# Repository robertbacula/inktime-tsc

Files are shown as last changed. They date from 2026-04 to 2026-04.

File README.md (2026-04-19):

# InkTime v6 - Smartwatch Open Hardware cu E-Paper

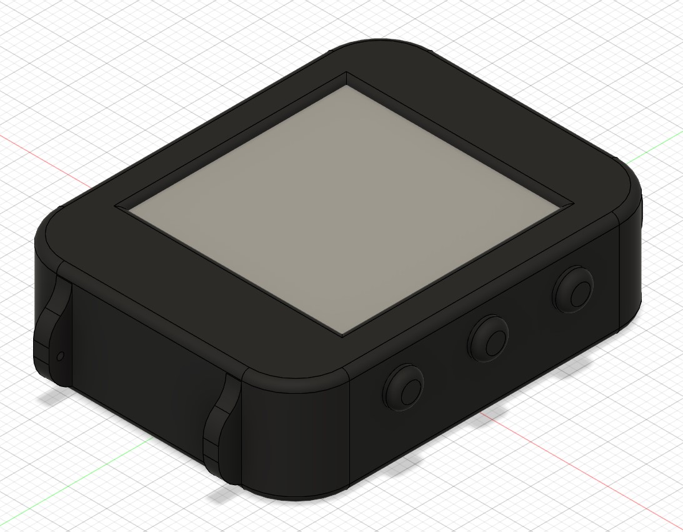
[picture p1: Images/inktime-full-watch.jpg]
InkTime - vedere generala


InkTime v6 este un proiect hardware open-source de smartwatch bazat pe nRF52840, optimizat pentru consum redus, autonomie mare si integrare mecanica compacta. Documentatia de mai jos este structurata pentru review tehnic si include arhitectura sistemului, BOM, maparea pinilor, analiza de consum si observatii de design.

## Cuprins

- [Diagrama bloc](#diagrama-bloc)
- [Bill of Materials (BOM)](#bill-of-materials-bom)
- [Functionalitate hardware detaliata](#functionalitate-hardware-detaliata)
- [Maparea pinilor nRF52840](#maparea-pinilor-nrf52840)
- [Analiza consumului de energie](#analiza-consumului-de-energie)
- [Design PCB si integrare mecanica](#design-pcb-si-integrare-mecanica)
- [Design log si observatii pentru review](#design-log-si-observatii-pentru-review)
- [Structura repository-ului](#structura-repository-ului)
- [Licenta](#licenta)

## Diagrama bloc

Diagrama bloc este prezentata ca imagine:

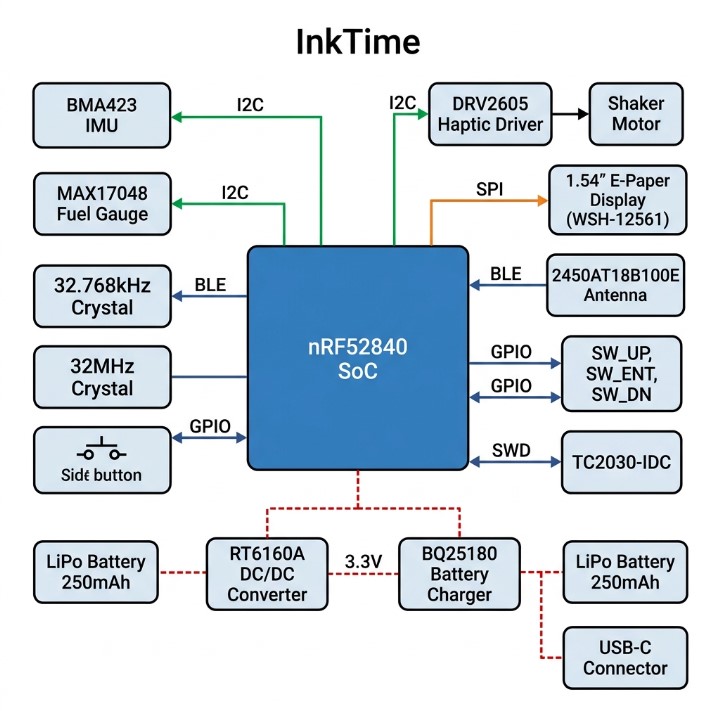
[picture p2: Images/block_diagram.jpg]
Diagrama bloc InkTime


Flux de functionare:

1. USB-C alimenteaza incarcatorul BQ25180 si bateria LiPo.
2. Din baterie se genereaza rail-ul de 3.3V (RT6160A), comutat catre sarcina prin PMOS.
3. nRF52840 colecteaza date de la IMU/fuel gauge si controleaza display-ul prin SPI.
4. Pentru notificari locale, nRF52840 activeaza DRV2605 care comanda motorul haptic.
5. BLE asigura schimb de date si configurare cu telefonul.

## Bill of Materials (BOM)

Tabelul de mai jos acopera componentele principale. Pentru pasivele individuale, consultati schema si listele de asamblare exportate din CAD.

| # | Ref  | Componenta | Cod / Valoare | JLC Parts | Datasheet |
| --- | ---- | --- | --- | --- | --- |
| 1 | U1 | MCU BLE | nRF52840-QIAA | [C190794](https://jlcpcb.com/parts/componentSearch?isSearch=true&searchTxt=nRF52840) | [nRF52840 PS](https://infocenter.nordicsemi.com/pdf/nRF52840_PS_v1.8.pdf) |
| 2 | IC2  | Li-Ion Charger | BQ25180YBGR | [C2682092](https://jlcpcb.com/parts/componentSearch?isSearch=true&searchTxt=BQ25180) | [TI BQ25180](https://www.ti.com/lit/ds/symlink/bq25180.pdf) |
| 3 | IC9  | Buck DC/DC | RT6160AWSC | [C2828036](https://jlcpcb.com/parts/componentSearch?isSearch=true&searchTxt=RT6160A) | [Richtek RT6160A](https://www.richtek.com/assets/product_file/RT6160A/DS6160A-05.pdf) |
| 4 | U3 | Fuel Gauge | MAX17048G+T10 | [C2682766](https://jlcpcb.com/parts/componentSearch?isSearch=true&searchTxt=MAX17048) | [MAX17048/49](https://datasheets.maximintegrated.com/en/ds/MAX17048-MAX17049.pdf) |
| 5 | IC3  | IMU | BMA423 | [C2831316](https://jlcpcb.com/parts/componentSearch?isSearch=true&searchTxt=BMA423) | [Bosch BMA423](https://www.bosch-sensortec.com/products/motion-sensors/accelerometers/bma423/) |
| 6 | IC1  | Driver haptic | DRV2605YZFR | [C527680](https://jlcpcb.com/parts/componentSearch?isSearch=true&searchTxt=DRV2605) | [TI DRV2605](https://www.ti.com/lit/ds/symlink/drv2605.pdf) |
| 7 | D1 | Protectie ESD USB | USBLC6-2SC6Y | [C7519](https://jlcpcb.com/parts/componentSearch?isSearch=true&searchTxt=USBLC6-2SC6Y) | [ST USBLC6-2](https://www.st.com/resource/en/datasheet/usblc6-2.pdf) |
| 8 | Q1 | PMOS load switch | DMG2305UX-7 | [C150812](https://jlcpcb.com/parts/componentSearch?isSearch=true&searchTxt=DMG2305UX) | [DMG2305UX](https://www.diodes.com/assets/Datasheets/DMG2305UX.pdf) |
| 9 | Q3 | N-MOS (motor/periferic) | SI1308EDL-T1-GE3  | [C515086](https://jlcpcb.com/parts/componentSearch?isSearch=true&searchTxt=SI1308EDL) | [SI1308EDL](https://www.vishay.com/docs/68743/si1308edl.pdf) |
| 10  | J1 | FPC conector EPD | 503480-2400 (24p) | [C585393](https://jlcpcb.com/parts/componentSearch?isSearch=true&searchTxt=503480-2400) | [Molex 503480](https://www.molex.com/pdm_docs/sd/5034802400_sd.pdf) |
| 11  | J4 | USB-C conector | KH-TYPE-C-16P | [C2765186](https://jlcpcb.com/parts/componentSearch?isSearch=true&searchTxt=KH-TYPE-C-16P) | [USB Type-C Spec](https://www.usb.org/document-library/usb-type-cr-cable-and-connector-specification-release-22) |
| 12  | ANT1 | Antena chip 2.4GHz | 2450AT18B100E | [Search JLC](https://jlcpcb.com/parts/componentSearch?isSearch=true&searchTxt=2450AT18B100E) | [Johanson 2450AT18B100E](https://www.johansontechnology.com/datasheets/2450AT18B100E.pdf) |
| 13  | J2 | Header debug | TC2030-IDC | [Search JLC](https://jlcpcb.com/parts/componentSearch?isSearch=true&searchTxt=TC2030) | [Tag-Connect TC2030](https://www.tag-connect.com/wp-content/uploads/bsk-pdf-manager/TC2030-IDC-NL-10_NL_1.pdf) |
| 14  | X1 | Cristal HF | 32MHz | [Search JLC](https://jlcpcb.com/parts/componentSearch?isSearch=true&searchTxt=32MHz%20crystal%202016) | [Exemplu 32MHz](https://www.ecsxtal.com/store/pdf/ECS-160-12-33Q.pdf) |
| 15  | X2 | Cristal LF | 32.768kHz | [Search JLC](https://jlcpcb.com/parts/componentSearch?isSearch=true&searchTxt=32.768kHz%20crystal%203215) | [Exemplu 32.768kHz](https://www.abracon.com/Resonators/ABS07.pdf) |

## Functionalitate hardware detaliata

### 1) Procesare si conectivitate - nRF52840

- CPU: ARM Cortex-M4F @ 64MHz
- Memorie: 1MB Flash, 256KB RAM
- Radio: BLE 5.x la 2.4GHz
- Interfete folosite in proiect: SPI, I2C, GPIO, USB FS, SWD

Rol functional:

- ruleaza logica aplicatiei si machine-state-ul ceasului
- centralizeaza datele de la senzori
- controleaza secventa de refresh pentru e-paper
- gestioneaza notificari BLE si feedback haptic

### 2) Display e-paper (1.54") + etaj driver

Display-ul e-paper este comandat pe SPI, cu semnale separate de control (`DC`, `RST`, `BUSY`, `CS`). Avantajul major este consumul aproape zero in stare statica; energia se consuma aproape exclusiv la refresh.

Interfata:

- SPI pentru payload grafic
- GPIO pentru sincronizare/stare (`BUSY`) si comenzi

### 3) IMU BMA423

IMU-ul este conectat pe I2C si utilizat pentru:

- step counting
- wake-on-motion / wrist raise
- detectie evenimente contextuale

Poate genera intreruperi catre MCU pentru reducerea polling-ului si optimizare de consum.

### 4) Management baterie - BQ25180 + MAX17048 + RT6160A

- BQ25180: incarcare LiPo din VBUS (USB-C)
- MAX17048: monitorizare starea bateriei (SOC, tensiune)
- RT6160A: conversie stabila catre 3.3V pentru sistem

Acest lant permite operare corecta atat pe USB, cat si pe baterie, cu telemetrie energetica pentru estimarea autonomiei.

### 5) Haptic - DRV2605 + motor

DRV2605 genereaza profile haptice controlate de MCU (I2C + trigger), iar etajul de putere comuta motorul pentru feedback la notificari, alarme si interactiuni UI.

### 6) USB-C, protectie ESD si debug

- USB-C ofera VBUS pentru incarcare si (optional) date USB FS.
- USBLC6-2 reduce riscul de defect la descarcari electrostatice pe D+/D-.
- Header-ul TC2030 expune SWD pentru flash/debug si test de productie.

## Maparea pinilor nRF52840

Maparea de mai jos este cea utilizata in schema proiectului pentru functiile principale.

| Pin nRF52840  | Semnal / Componenta | Interfata | Directie | Motiv alegere |
| --- | --- | --- | --- | --- |
| P0.02 | EPD_SCK | SPI | Out | Clock stabil pentru transfer display |
| P0.03 | EPD_MOSI | SPI | Out | Date catre e-paper |
| P0.28 | EPD_MISO | SPI | In | Citire status/date display |
| P0.29 | EPD_CS | GPIO/SPI  | Out | Selectie dispozitiv e-paper |
| P0.04 | EPD_DC | GPIO | Out | Selectie data/comanda |
| P0.05 | EPD_RST | GPIO | Out | Reset hardware display |
| P0.06 | EPD_BUSY | GPIO | In | Sincronizare pe stare busy |
| P0.26 | I2C_SDA | I2C | I/O | Magistrala comuna senzori/power |
| P0.27 | I2C_SCL | I2C | Out | Clock I2C comun |
| P0.13 | SW_UP | GPIO IRQ  | In | Buton up, interrupt la apasare |
| P0.14 | SW_ENT | GPIO IRQ  | In | Buton enter, UI action |
| P0.15 | SW_DN | GPIO IRQ  | In | Buton down, navigare |
| P0.18 | USB_D- | USB FS | I/O | Linie USB dedicata (minus) |
| P0.20 | USB_D+ | USB FS | I/O | Linie USB dedicata (plus) |
| P0.00 / P0.01 | XL1 / XL2 | LFCLK | I/O | Cristal 32.768kHz pentru RTC low-power |
| XC1 / XC2 | X1 32MHz | HFCLK | I/O | Ceas principal CPU/RF |
| SWDIO | SWD_DATA | SWD | I/O | Programare si debugging |
| SWDCLK | SWD_CLK | SWD | In | Ceas SWD |
| SWO | SWO_TRACE | SWD | Out | Trace/telemetrie debug |
| ANT | Antena BLE | RF | Out | Iesire RF catre retea de matching |

Rationale general pentru mapare:

1. SPI-ul display-ului este grupat compact pentru rutare scurta si integritate buna a semnalelor.
2. Toate perifericele lente (IMU, fuel gauge, haptic) sunt pe I2C comun pentru economie de pini.
3. Butoanele sunt pe GPIO-uri configurabile cu intreruperi, pentru wake-up din low power.
4. USB foloseste pinii dedicati ai MCU pentru compatibilitate fizica si software.

## Analiza consumului de energie

Estimare orientativa pe scenariu "smartwatch normal" (ecran actualizat periodic, BLE advertising, wake pe evenimente):

| Bloc | Curent activ | Curent sleep/idle | Duty cycle estimat | Curent mediu |
| --- | ---: | ---: | ---: | ---: |
| nRF52840 (CPU + BLE) |  3.2mA-4.8mA | 1.5uA | 5-6% | ~210uA |
| E-Paper (refresh) | ~15mA | ~0uA static | 0.5% | ~75uA |
| BMA423 | ~150uA | ~14uA | 10% activ | ~28uA |
| MAX17048 | 23uA | 23uA | 100% | 23uA |
| DRV2605 + motor | ~50mA varf | ~0.25uA | 0.1% | ~50uA |
| RT6160A quiescent | - | ~25uA | 100% | 25uA |
| **Total estimat** | - | - | - | **~410uA** |

Pentru baterie de 250mAh:

- autonomie teoretica: `250mAh / 0.41mA = ~609h` (~25 zile)
- cu profil agresiv de sleep si refresh rar: 30-40+ zile (in functie de firmware si trafic BLE)

## Design PCB si integrare mecanica

### PCB

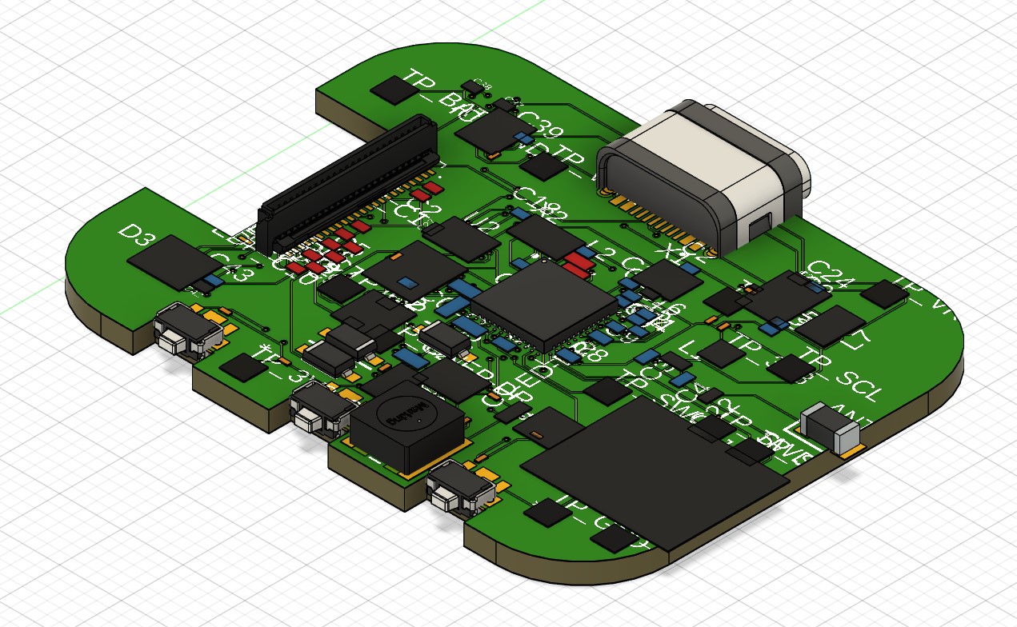
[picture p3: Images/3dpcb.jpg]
PCB 3D


- layout realizat in fisierele `Hardware/project-tsc.sch` si `Hardware/project-tsc-2d-pcb.brd`
- topologia include zona RF dedicata, sectiune alimentare separata si trasee de semnal scurte catre conectorul EPD
- protectie ESD pe USB si puncte de test pentru bring-up

### Integrare mecanica

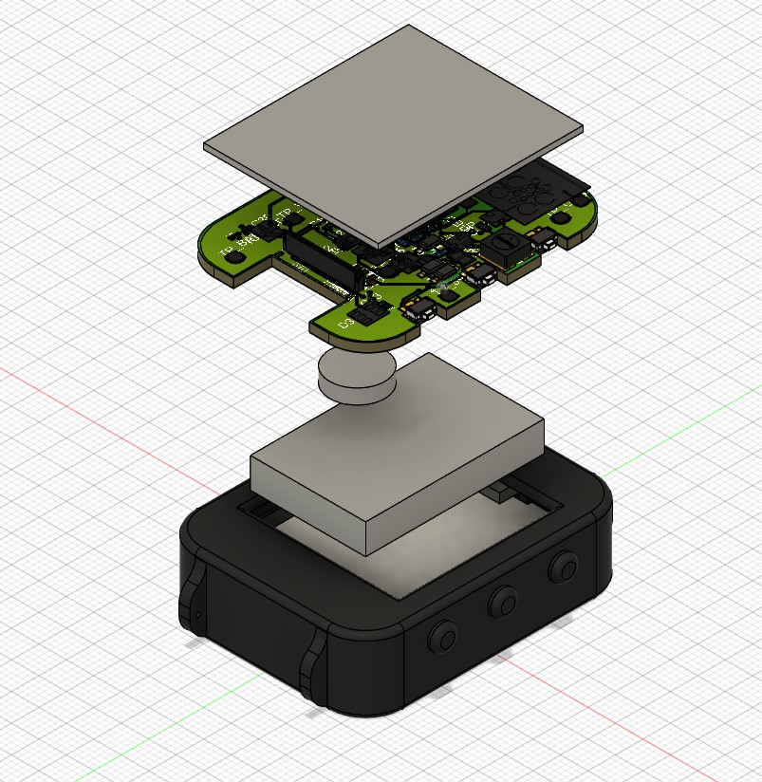
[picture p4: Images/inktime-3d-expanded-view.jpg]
Vedere asamblare extinsa

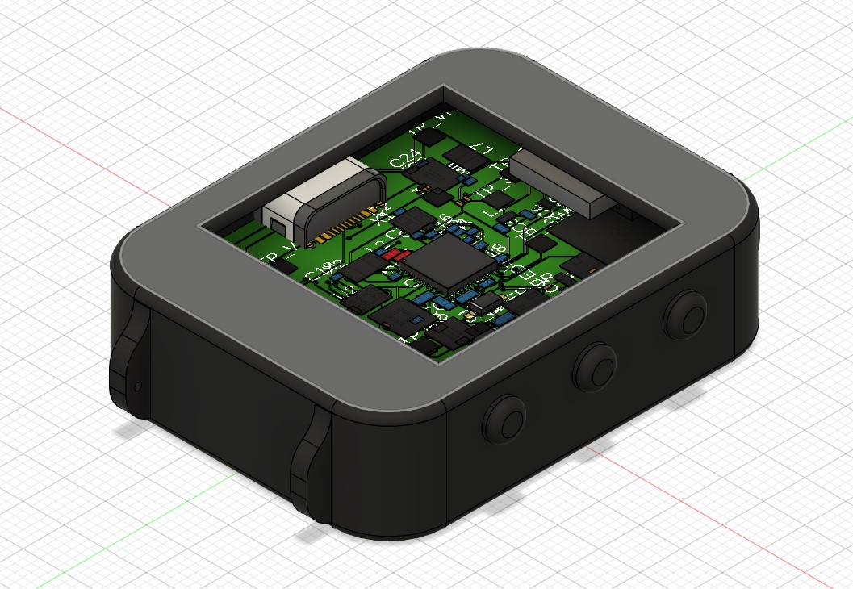
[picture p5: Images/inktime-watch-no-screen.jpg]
Vedere fara ecran


- modele 3D disponibile in `Mechanical/InkTime3D.f3z` si `Mechanical/InkTime3D.step`
- verificari importante: inaltime baterie, spatiu FPC display, pozitie butoane laterale, clearance pentru motorul haptic

## Design log si observatii pentru review

Design log (sintetic):

1. Definire arhitectura (MCU, putere, senzori, afisaj)
2. Captura schema si validare ERC
3. Placement cu prioritizare RF/power/display
4. Routing + optimizari DRC/ground return
5. Export productie si validare mecanica 3D

Observatii utile pentru review:

- verificati zona antenei: keepout de cupru sub antenna + matching network conform recomandari vendor
- confirmati polaritatea pentru bateria LiPo si sensul diodei Schottky
- verificati secventa de power-up EPD in firmware, pentru a evita refresh instabil
- recomandat test incremental: power rail -> SWD -> I2C -> EPD -> BLE

## Structura repository-ului

```text
inktime-tsc/
|- Hardware/
|  |- project-tsc.sch
|  |- project-tsc-2d-pcb.brd
|- Images/
|  |- 3dpcb.jpg
|  |- inktime-full-watch.jpg
|  |- inktime-3d-expanded-view.jpg
|  |- inktime-watch-no-screen.jpg
|- Manufacturing/
|  |- inktime_gerber.zip
|- Mechanical/
|  |- InkTime3D.f3z
|  |- InkTime3D.step
|- LICENSE
|- README.md
```

## Licenta

Proiectul este distribuit conform fisierului `LICENSE` din acest repository.

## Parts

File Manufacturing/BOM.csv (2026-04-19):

Part | Value | Device | Footprint Name | Detailed Description | ARROW_PART_NUMBER | ARROW_PRICE-STOCK | AVAILABILITY | CHECK_PRICES | COPYRIGHT | DESCRIPTION | DIGI-KEY_PART_NUMBER_1 | DIGI-KEY_PART_NUMBER_2 | DIGI-KEY_PART_NUMBER_3 | HEIGHT | JLCPCB | MANUFACTURER_NAME | MANUFACTURER_PART_NUMBER | MF | MFR_NAME | MOUSER_PART_NUMBER | MOUSER_PRICE-STOCK | MP | PACKAGE | POPULARITY | PRICE | PROD_ID | PURCHASE-URL | SNAPEDA_LINK | TP_SIGNAL_NAME | VALUE
ANT1 | 2450AT18B100E | 2450AT18B100E_2450AT18B100E | 2450AT18B100E_ANTC3216X140N | Antennas 2.45GHz ANTENNA | 2450AT18B100E | https://www.arrow.com/en/products/2450at18b100e/johanson-dielectrics?utm_currency=USD&region=nac |  |  |  | Antennas 2.45GHz ANTENNA |  |  |  | 1.4mm |  | JOHANSON TECHNOLOGY | 2450AT18B100E |  |  | 609-2450AT18B100E | https://www.mouser.co.uk/ProductDetail/Johanson-Technology/2450AT18B100E?qs=yCnrNFeXz%252Bh5MFsFIXGZGA%3D%3D
C1 | 12pF | NORDIC_NRF_3_CAPACITOR_0201_L | NORDIC_NRF_3_RESC0201_L | Generic chip capacitor
C1-ED-DR | 10uF | NORDIC_NRF_3_CAPACITOR_0402_N | NORDIC_NRF_3_RESC0402_N | Generic chip capacitor
C2 | 12pF | NORDIC_NRF_3_CAPACITOR_0201_L | NORDIC_NRF_3_RESC0201_L | Generic chip capacitor
C2-EP-DR | 4.7uF | NORDIC_NRF_3_CAPACITOR_0402_N | NORDIC_NRF_3_RESC0402_N | Generic chip capacitor
C3 | 1pF | NORDIC_NRF_3_CAPACITOR_0201_N | NORDIC_NRF_3_RESC0201_N | Generic chip capacitor
C4 | 1pF | NORDIC_NRF_3_CAPACITOR_0201_N | NORDIC_NRF_3_RESC0201_N | Generic chip capacitor
C5 | 100nF | NORDIC_NRF_3_CAPACITOR_0201_L | NORDIC_NRF_3_RESC0201_L | Generic chip capacitor
C6 | 4.7uF | NORDIC_NRF_3_CAPACITOR_0402_N | NORDIC_NRF_3_RESC0402_N | Generic chip capacitor
C7 | 100nF | NORDIC_NRF_3_CAPACITOR_0201_N | NORDIC_NRF_3_RESC0201_N | Generic chip capacitor
C8 | 100nF | NORDIC_NRF_3_CAPACITOR_0201_N | NORDIC_NRF_3_RESC0201_N | Generic chip capacitor
C9 | 820pF | NORDIC_NRF_3_CAPACITOR_0201_N | NORDIC_NRF_3_RESC0201_N | Generic chip capacitor
C10 | N.C. | NORDIC_NRF_3_CAPACITOR_0201_L | NORDIC_NRF_3_RESC0201_L | Generic chip capacitor
C11 | 100pF | NORDIC_NRF_3_CAPACITOR_0201_L | NORDIC_NRF_3_RESC0201_L | Generic chip capacitor
C12 | 100nF | NORDIC_NRF_3_CAPACITOR_0201_L | NORDIC_NRF_3_RESC0201_L | Generic chip capacitor
C13 | N.C. | NORDIC_NRF_3_CAPACITOR_0201_L | NORDIC_NRF_3_RESC0201_L | Generic chip capacitor
C14 | 4.7uF | NORDIC_NRF_3_CAPACITOR_0201_L | NORDIC_NRF_3_RESC0201_L | Generic chip capacitor
C15 | 1.0uF | NORDIC_NRF_3_CAPACITOR_0201_L | NORDIC_NRF_3_RESC0201_L | Generic chip capacitor
C16 | 47nF | NORDIC_NRF_3_CAPACITOR_0201_L | NORDIC_NRF_3_RESC0201_L | Generic chip capacitor
C17 | 12pF | NORDIC_NRF_3_CAPACITOR_0201_L | NORDIC_NRF_3_RESC0201_L | Generic chip capacitor
C18\ | 12pF | NORDIC_NRF_3_CAPACITOR_0201_L | NORDIC_NRF_3_RESC0201_L | Generic chip capacitor
C19 | 100nF | NORDIC_NRF_3_CAPACITOR_0201_L | NORDIC_NRF_3_RESC0201_L | Generic chip capacitor
C20 | 4.7uF | NORDIC_NRF_3_CAPACITOR_0402_N | NORDIC_NRF_3_RESC0402_N | Generic chip capacitor
C21 | 4.7uF | NORDIC_NRF_3_CAPACITOR_0402_N | NORDIC_NRF_3_RESC0402_N | Generic chip capacitor
C22 | N.C. | NORDIC_NRF_3_CAPACITOR_0201_N | NORDIC_NRF_3_RESC0201_N | Generic chip capacitor
C23 | 0.1uF | GRM011R60J152KE01L_2_GRM011R60J152KE01L | GRM011R60J152KE01L_2_CAPC0201X13N | Check availability |  |  | In Stock | https://www.snapeda.com/parts/GRM011R60J152KE01L/Murata/view-part/?ref=eda |  | SMD Capacitor X5R(EIA) with Capacitance: 1500pF Tol. 10%. Rated Voltage: 6.3Vdc |  |  |  |  |  |  |  | Murata |  |  |  | GRM011R60J152KE01L | 0201 Murata |  | None |  |  | https://www.snapeda.com/parts/GRM011R60J152KE01L/Murata/view-part/?ref=snap
C24 | 10uF | NORDIC_NRF_3_CAPACITOR_0201_L | NORDIC_NRF_3_RESC0201_L | Generic chip capacitor
C25 | 22uF | NORDIC_NRF_3_CAPACITOR_0201_L | NORDIC_NRF_3_RESC0201_L | Generic chip capacitor
C27 | 0.1uF | GRM011R60J152KE01L_2_GRM011R60J152KE01L | GRM011R60J152KE01L_2_CAPC0201X13N | Check availability |  |  | In Stock | https://www.snapeda.com/parts/GRM011R60J152KE01L/Murata/view-part/?ref=eda |  | SMD Capacitor X5R(EIA) with Capacitance: 1500pF Tol. 10%. Rated Voltage: 6.3Vdc |  |  |  |  |  |  |  | Murata |  |  |  | GRM011R60J152KE01L | 0201 Murata |  | None |  |  | https://www.snapeda.com/parts/GRM011R60J152KE01L/Murata/view-part/?ref=snap
C29 | 1uF | GRM011R60J152KE01L_2_GRM011R60J152KE01L | GRM011R60J152KE01L_2_CAPC0201X13N | Check availability |  |  | In Stock | https://www.snapeda.com/parts/GRM011R60J152KE01L/Murata/view-part/?ref=eda |  | SMD Capacitor X5R(EIA) with Capacitance: 1500pF Tol. 10%. Rated Voltage: 6.3Vdc |  |  |  |  |  |  |  | Murata |  |  |  | GRM011R60J152KE01L | 0201 Murata |  | None |  |  | https://www.snapeda.com/parts/GRM011R60J152KE01L/Murata/view-part/?ref=snap
C30 | 1uF | GRM011R60J152KE01L_2_GRM011R60J152KE01L | GRM011R60J152KE01L_2_CAPC0201X13N | Check availability |  |  | In Stock | https://www.snapeda.com/parts/GRM011R60J152KE01L/Murata/view-part/?ref=eda |  | SMD Capacitor X5R(EIA) with Capacitance: 1500pF Tol. 10%. Rated Voltage: 6.3Vdc |  |  |  |  |  |  |  | Murata |  |  |  | GRM011R60J152KE01L | 0201 Murata |  | None |  |  | https://www.snapeda.com/parts/GRM011R60J152KE01L/Murata/view-part/?ref=snap
C31 | 1uF | GRM011R60J152KE01L_2_GRM011R60J152KE01L | GRM011R60J152KE01L_2_CAPC0201X13N | Check availability |  |  | In Stock | https://www.snapeda.com/parts/GRM011R60J152KE01L/Murata/view-part/?ref=eda |  | SMD Capacitor X5R(EIA) with Capacitance: 1500pF Tol. 10%. Rated Voltage: 6.3Vdc |  |  |  |  |  |  |  | Murata |  |  |  | GRM011R60J152KE01L | 0201 Murata |  | None |  |  | https://www.snapeda.com/parts/GRM011R60J152KE01L/Murata/view-part/?ref=snap
C32 | 1uF | GRM011R60J152KE01L_2_GRM011R60J152KE01L | GRM011R60J152KE01L_2_CAPC0201X13N | Check availability |  |  | In Stock | https://www.snapeda.com/parts/GRM011R60J152KE01L/Murata/view-part/?ref=eda |  | SMD Capacitor X5R(EIA) with Capacitance: 1500pF Tol. 10%. Rated Voltage: 6.3Vdc |  |  |  |  |  |  |  | Murata |  |  |  | GRM011R60J152KE01L | 0201 Murata |  | None |  |  | https://www.snapeda.com/parts/GRM011R60J152KE01L/Murata/view-part/?ref=snap
C33 | 22uF | NORDIC_NRF_3_CAPACITOR_0201_L | NORDIC_NRF_3_RESC0201_L | Generic chip capacitor
C34 | 0.1uF | GRM011R60J152KE01L_2_GRM011R60J152KE01L | GRM011R60J152KE01L_2_CAPC0201X13N | Check availability |  |  | In Stock | https://www.snapeda.com/parts/GRM011R60J152KE01L/Murata/view-part/?ref=eda |  | SMD Capacitor X5R(EIA) with Capacitance: 1500pF Tol. 10%. Rated Voltage: 6.3Vdc |  |  |  |  |  |  |  | Murata |  |  |  | GRM011R60J152KE01L | 0201 Murata |  | None |  |  | https://www.snapeda.com/parts/GRM011R60J152KE01L/Murata/view-part/?ref=snap
C37 | 1uF | GRM011R60J152KE01L_2_GRM011R60J152KE01L | GRM011R60J152KE01L_2_CAPC0201X13N | Check availability |  |  | In Stock | https://www.snapeda.com/parts/GRM011R60J152KE01L/Murata/view-part/?ref=eda |  | SMD Capacitor X5R(EIA) with Capacitance: 1500pF Tol. 10%. Rated Voltage: 6.3Vdc |  |  |  |  |  |  |  | Murata |  |  |  | GRM011R60J152KE01L | 0201 Murata |  | None |  |  | https://www.snapeda.com/parts/GRM011R60J152KE01L/Murata/view-part/?ref=snap
C38 | 1uF | GRM011R60J152KE01L_2_GRM011R60J152KE01L | GRM011R60J152KE01L_2_CAPC0201X13N | Check availability |  |  | In Stock | https://www.snapeda.com/parts/GRM011R60J152KE01L/Murata/view-part/?ref=eda |  | SMD Capacitor X5R(EIA) with Capacitance: 1500pF Tol. 10%. Rated Voltage: 6.3Vdc |  |  |  |  |  |  |  | Murata |  |  |  | GRM011R60J152KE01L | 0201 Murata |  | None |  |  | https://www.snapeda.com/parts/GRM011R60J152KE01L/Murata/view-part/?ref=snap
C39 | 10uF | NORDIC_NRF_3_CAPACITOR_0201_L | NORDIC_NRF_3_RESC0201_L | Generic chip capacitor
C42 | 0.1uF | GRM011R60J152KE01L_2_GRM011R60J152KE01L | GRM011R60J152KE01L_2_CAPC0201X13N | Check availability |  |  | In Stock | https://www.snapeda.com/parts/GRM011R60J152KE01L/Murata/view-part/?ref=eda |  | SMD Capacitor X5R(EIA) with Capacitance: 1500pF Tol. 10%. Rated Voltage: 6.3Vdc |  |  |  |  |  |  |  | Murata |  |  |  | GRM011R60J152KE01L | 0201 Murata |  | None |  |  | https://www.snapeda.com/parts/GRM011R60J152KE01L/Murata/view-part/?ref=snap
C43 | 4.7uF | NORDIC_NRF_3_CAPACITOR_0201_L | NORDIC_NRF_3_RESC0201_L | Generic chip capacitor
D2 | MBR0530 | ESP32_C6_LIBRARY_5_MBR0530 | ESP32_C6_LIBRARY_5_SOD3716X135N | ON SEMICONDUCTOR - MBR0530 - DIODE, SCHOTTKY, 0.5A, 30V, SOD-123 |  |  | In Stock | https://www.snapeda.com/parts/MBR0530/Onsemi/view-part/?ref=eda |  | Diode Schottky 30 V 500mA Surface Mount SOD-123 |  |  |  |  |  |  |  | ON Semiconductor |  |  |  | MBR0530 | SOD-123-2 ON Semiconductor |  | None |  | https://www.snapeda.com/api/url_track_click_mouser/?unipart_id=179458&manufacturer=ON Semiconductor&part_name=MBR0530&search_term=None | https://www.snapeda.com/parts/MBR0530/Onsemi/view-part/?ref=snap
D3 | USBLC6-2SC6Y | ESP32_C6_LIBRARY_3_USBLC6-2SC6Y | ESP32_C6_LIBRARY_3_SOT95P280X145-6N | Low Cap. ESD Protection Auto SOT-23-6 STMicroelectronics USBLC6-2SC6Y, Dual Uni-Directional TVS Diode Array, 6-Pin SOT-23 |  |  | In Stock | https://www.snapeda.com/parts/USBLC6-2SC6Y/STMicroelectronics/view-part/?ref=eda |  | 17V Clamp 5A (8/20µs) Ipp Tvs Diode Surface Mount SOT-23-6 |  |  |  |  |  |  |  | STMicroelectronics |  |  |  | USBLC6-2SC6Y | SOT-23-6 STMicroelectronics |  | None |  |  | https://www.snapeda.com/parts/USBLC6-2SC6Y/STMicroelectronics/view-part/?ref=snap
D4 | MBR0530 | ESP32_C6_LIBRARY_5_MBR0530 | ESP32_C6_LIBRARY_5_SOD3716X135N | ON SEMICONDUCTOR - MBR0530 - DIODE, SCHOTTKY, 0.5A, 30V, SOD-123 |  |  | In Stock | https://www.snapeda.com/parts/MBR0530/Onsemi/view-part/?ref=eda |  | Diode Schottky 30 V 500mA Surface Mount SOD-123 |  |  |  |  |  |  |  | ON Semiconductor |  |  |  | MBR0530 | SOD-123-2 ON Semiconductor |  | None |  | https://www.snapeda.com/api/url_track_click_mouser/?unipart_id=179458&manufacturer=ON Semiconductor&part_name=MBR0530&search_term=None | https://www.snapeda.com/parts/MBR0530/Onsemi/view-part/?ref=snap
D5 | MBR0530 | ESP32_C6_LIBRARY_5_MBR0530 | ESP32_C6_LIBRARY_5_SOD3716X135N | ON SEMICONDUCTOR - MBR0530 - DIODE, SCHOTTKY, 0.5A, 30V, SOD-123 |  |  | In Stock | https://www.snapeda.com/parts/MBR0530/Onsemi/view-part/?ref=eda |  | Diode Schottky 30 V 500mA Surface Mount SOD-123 |  |  |  |  |  |  |  | ON Semiconductor |  |  |  | MBR0530 | SOD-123-2 ON Semiconductor |  | None |  | https://www.snapeda.com/api/url_track_click_mouser/?unipart_id=179458&manufacturer=ON Semiconductor&part_name=MBR0530&search_term=None | https://www.snapeda.com/parts/MBR0530/Onsemi/view-part/?ref=snap
EDP_C1 | 10uF | NORDIC_NRF_3_CAPACITOR_0201_L | NORDIC_NRF_3_RESC0201_L | Generic chip capacitor
EDP_C2 | 10uF | NORDIC_NRF_3_CAPACITOR_0201_L | NORDIC_NRF_3_RESC0201_L | Generic chip capacitor
EDP_C5 | 0.1uF/50V | NORDIC_NRF_3_CAPACITOR_0201_L | NORDIC_NRF_3_RESC0201_L | Generic chip capacitor
EDP_C6 | 1uF/50V | NORDIC_NRF_3_CAPACITOR_0201_L | NORDIC_NRF_3_RESC0201_L | Generic chip capacitor
EDP_C7 | 1uF/50V | NORDIC_NRF_3_CAPACITOR_0201_L | NORDIC_NRF_3_RESC0201_L | Generic chip capacitor
EDP_C8 | 1uF/50V | NORDIC_NRF_3_CAPACITOR_0201_L | NORDIC_NRF_3_RESC0201_L | Generic chip capacitor
EDP_C9 | 1uF/50V | NORDIC_NRF_3_CAPACITOR_0201_L | NORDIC_NRF_3_RESC0201_L | Generic chip capacitor
EDP_C10 | 1uF/50V | NORDIC_NRF_3_CAPACITOR_0201_L | NORDIC_NRF_3_RESC0201_L | Generic chip capacitor
EDP_C11 | 1uF/50V | NORDIC_NRF_3_CAPACITOR_0201_L | NORDIC_NRF_3_RESC0201_L | Generic chip capacitor
EDP_C12 | 1uF/50V | NORDIC_NRF_3_CAPACITOR_0201_L | NORDIC_NRF_3_RESC0201_L | Generic chip capacitor
IC1 | BQ25180YBGR | BQ25180YBGR_BQ25180YBGR | BQ25180YBGR_BGA8C40P2X4_100X155X50 | Charger IC Lithium Ion/Polymer, Lithium Iron Phosphate 8-DSBGA (1.6x1.1) | BQ25180YBGR | https://www.arrow.com/en/products/bq25180ybgr/texas-instruments?utm_currency=USD&region=nac |  |  |  | Charger IC Lithium Ion/Polymer, Lithium Iron Phosphate 8-DSBGA (1.6x1.1) |  |  |  | 0.5mm |  | Texas Instruments | BQ25180YBGR |  |  | 595-BQ25180YBGR | https://www.mouser.co.uk/ProductDetail/Texas-Instruments/BQ25180YBGR?qs=doiCPypUmgEWjAK%252BJAX6Tw%3D%3D
IC2 | DRV2605YZFR | DRV2605YZFR_DRV2605YZFR | DRV2605YZFR_BGA9C50P3X3_144X144X62 | Haptic Driver for ERM/LRA with Built-In Library and Smart Loop Architecture | DRV2605YZFR | https://www.arrow.com/en/products/drv2605yzfr/texas-instruments?region=nac |  |  |  | Haptic Driver for ERM/LRA with Built-In Library and Smart Loop Architecture |  |  |  | 0.625mm |  | Texas Instruments | DRV2605YZFR
IC3 | BMA421 | BMA423_BMA423 | BMA423_BMA423 | Accelerometers Triaxial low-g 12bit Acceleration Sensor | BMA423 | https://www.arrow.com/en/products/bma423/bosch |  |  |  | Accelerometers Triaxial low-g 12bit Acceleration Sensor |  |  |  | 1mm |  | BOSCH | BMA423 |  |  | 262-BMA423 | https://www.mouser.co.uk/ProductDetail/Bosch-Sensortec/BMA423?qs=HXFqYaX1Q2xC%252BSgeGoX3mg%3D%3D
IC9 | RT6160AWSC | RT6160AWSC_RT6160AWSC | RT6160AWSC_BGA15C40P3X5_140X230X60 | Buck-Boost Regulator Positive Output Step-Up/Step-Down I2C DC-DC Controller IC 15-WL-CSP (BSC) (1.4x2.3) |  |  |  |  |  | Buck-Boost Regulator Positive Output Step-Up/Step-Down I2C DC-DC Controller IC 15-WL-CSP (BSC) (1.4x2.3) |  |  |  | 0.6mm |  | RICHTEK | RT6160AWSC |  |  | 835-RT6160AWSC | https://www.mouser.co.uk/ProductDetail/Richtek/RT6160AWSC?qs=amGC7iS6iy%2FLd9PSoixZXQ%3D%3D
J1 | TC2030-IDC_TC2030-IDC | TC2030-IDC_TC2030-IDC | TC2030-IDC_TC2030IDC | CABLE ADAPTER 6 POS |  |  |  |  |  | CABLE ADAPTER 6 POS |  |  |  | 19mm |  | Tag Connect | TC2030-IDC
J2 | 503480-2400_503480-2400 | 503480-2400_503480-2400 | 503480-2400_5034802400 | FFC & FPC Connectors 0.5mm FPC RA SMT Dual Contact 24Ckt |  |  |  |  |  | FFC & FPC Connectors 0.5mm FPC RA SMT Dual Contact 24Ckt |  |  |  | 1.87mm |  | Molex | 503480-2400 |  |  | 538-503480-2400 | https://www.mouser.co.uk/ProductDetail/Molex/503480-2400?qs=OAhjpuo3Vu7efIoxFh9AOw%3D%3D
J4 | KH-TYPE-C-16P | KH-TYPE-C-16P_KH-TYPE-C-16P | KH-TYPE-C-16P_KINGHELM_KH-TYPE-C-16P | Check availability |  |  | Not in stock | https://www.snapeda.com/parts/KH-TYPE-C-16P/Kinghelm/view-part/?ref=eda |  |  |  |  |  |  |  |  |  | kinghelm |  |  |  | KH-TYPE-C-16P | None |  | None |  |  | https://www.snapeda.com/parts/KH-TYPE-C-16P/Kinghelm/view-part/?ref=snap
L1 | 3.9nH | NORDIC_NRF_2_INDUCTOR_0402_L | NORDIC_NRF_2_RESC0402_L | Generic chip inductor
L2 | 10uH | NORDIC_NRF_2_INDUCTOR_0402_L | NORDIC_NRF_2_RESC0402_L | Generic chip inductor
L3\ | 15nH | NORDIC_NRF_2_INDUCTOR_0402_L | NORDIC_NRF_2_RESC0402_L | Generic chip inductor
L5 | 68uH | ESP32_C6_LIBRARY_2_744043680IND_4828-WE-TPC_WRE | ESP32_C6_LIBRARY_2_IND_4828-WE-TPC_WRE |  |  |  |  |  | Copyright (C) 2024 Ultra Librarian. All rights reserved. |  |  |  |  |  |  |  | 744043680 |  | Wurth Electronics
L7 | FTC252012SR47MBCA | MLP2016SR47MT0S1_FTC252012SR47MBCA | MLP2016SR47MT0S1_INDC2016X100N | SMD / SMT Inductors (Coils), L=0.47?H, L x W x T : |  |  |  |  |  | SMD / SMT Inductors (Coils), L=0.47?H, L x W x T : |  |  |  | 1mm | https://jlcpcb.com/partdetail/6763488-FTC252012SR47MBCA/C5832368 | TDK | FTC252012SR47MBCA
Q1 | 20V/4.2A/52mO/1.4W | ESP32_C6_LIBRARY_4_ESP32_WROVER_SPARKFUN-DISCRETESEMI_MOSFET_PCH-DMG2305UX-7 | ESP32_C6_LIBRARY_4_ESP32_C6_LIBRARY_4_ESP32_C6_LIBRARY_4_ESP32_C6_LIBRARY_4_ESP32_WROVER_SPARKFUN-DISCRETESEMI_SOT23-3 | P-channel MOSFETs |  |  |  |  |  |  |  |  |  |  |  |  |  |  |  |  |  |  |  |  |  | TRAN-14388 |  |  |  | 20V/4.2A/52mO/1.4W
Q3 | SI1308EDL-T1-GE3 | ESP32_C6_LIBRARY_6_SI1308EDL-T1-GE3 | ESP32_C6_LIBRARY_6_SOT65P210X110-3N | MOSFET N-Ch 30V 1.5A TrenchFET SC70 Vishay Si1308EDL-T1-GE3 N-channel MOSFET Transistor, 1.5 A, 30 V, 3-Pin SC-70 |  |  | In Stock | https://www.snapeda.com/parts/SI1308EDL-T1-GE3/Vishay+Siliconix/view-part/?ref=eda |  | Si1308EDL-T1-GE3 N-channel MOSFET Transistor, 1.5 A, 30 V, 3-Pin SC-70 | Siliconix / Vishay SI1308EDL-T1-GE3 |  |  |  |  |  |  |  | Vishay Siliconix |  |  |  | SI1308EDL-T1-GE3 | SOT-323 Vishay Semiconductor |  | None |  | https://www.snapeda.com/api/url_track_click_mouser/?unipart_id=274603&manufacturer=Vishay Siliconix&part_name=SI1308EDL-T1-GE3&search_term=None | https://www.snapeda.com/parts/SI1308EDL-T1-GE3/Vishay+Siliconix/view-part/?ref=snap
R1 | 10K | CPF0201D7K68C1_CPF0201D7K68C1 | CPF0201D7K68C1_0201 | 7.68k 0201 Thin Film Surface Mount Fixed Resistor +/-0.5% 0.031W CPF0201D7K68C1
R1_EP_DR1 | 0.47 | CPF0201D7K68C1_CPF0201D7K68C1 | CPF0201D7K68C1_0201 | 7.68k 0201 Thin Film Surface Mount Fixed Resistor +/-0.5% 0.031W CPF0201D7K68C1
R1_USB | 5K1 | CPF0201D7K68C1_CPF0201D7K68C1 | CPF0201D7K68C1_0201 | 7.68k 0201 Thin Film Surface Mount Fixed Resistor +/-0.5% 0.031W CPF0201D7K68C1
R2 | 10K | CPF0201D7K68C1_CPF0201D7K68C1 | CPF0201D7K68C1_0201 | 7.68k 0201 Thin Film Surface Mount Fixed Resistor +/-0.5% 0.031W CPF0201D7K68C1
R2_EP_DR | 10K | CPF0201D7K68C1_CPF0201D7K68C1 | CPF0201D7K68C1_0201 | 7.68k 0201 Thin Film Surface Mount Fixed Resistor +/-0.5% 0.031W CPF0201D7K68C1
R2_USB | 5K1 | CPF0201D7K68C1_CPF0201D7K68C1 | CPF0201D7K68C1_0201 | 7.68k 0201 Thin Film Surface Mount Fixed Resistor +/-0.5% 0.031W CPF0201D7K68C1
R3 | 0 | CPF0201D7K68C1_CPF0201D7K68C1 | CPF0201D7K68C1_0201 | 7.68k 0201 Thin Film Surface Mount Fixed Resistor +/-0.5% 0.031W CPF0201D7K68C1
R5 | 10K | CPF0201D7K68C1_CPF0201D7K68C1 | CPF0201D7K68C1_0201 | 7.68k 0201 Thin Film Surface Mount Fixed Resistor +/-0.5% 0.031W CPF0201D7K68C1
R7 | 10K | CPF0201D7K68C1_CPF0201D7K68C1 | CPF0201D7K68C1_0201 | 7.68k 0201 Thin Film Surface Mount Fixed Resistor +/-0.5% 0.031W CPF0201D7K68C1
R8 | 10K | CPF0201D7K68C1_CPF0201D7K68C1 | CPF0201D7K68C1_0201 | 7.68k 0201 Thin Film Surface Mount Fixed Resistor +/-0.5% 0.031W CPF0201D7K68C1
R9 | 10K | CPF0201D7K68C1_CPF0201D7K68C1 | CPF0201D7K68C1_0201 | 7.68k 0201 Thin Film Surface Mount Fixed Resistor +/-0.5% 0.031W CPF0201D7K68C1
R17 | 3K3 | CPF0201D7K68C1_CPF0201D7K68C1 | CPF0201D7K68C1_0201 | 7.68k 0201 Thin Film Surface Mount Fixed Resistor +/-0.5% 0.031W CPF0201D7K68C1
R18 | 3K3 | CPF0201D7K68C1_CPF0201D7K68C1 | CPF0201D7K68C1_0201 | 7.68k 0201 Thin Film Surface Mount Fixed Resistor +/-0.5% 0.031W CPF0201D7K68C1
R_PWR_EPD | 10K | CPF0201D7K68C1_CPF0201D7K68C1 | CPF0201D7K68C1_0201 | 7.68k 0201 Thin Film Surface Mount Fixed Resistor +/-0.5% 0.031W CPF0201D7K68C1
R_TYPE_SEL | 2.2 | CPF0201D7K68C1_CPF0201D7K68C1 | CPF0201D7K68C1_0201 | 7.68k 0201 Thin Film Surface Mount Fixed Resistor +/-0.5% 0.031W CPF0201D7K68C1
SJ1 |  | ESP32_C6_LIBRARY_7_JUMPER_SJ | ESP32_C6_LIBRARY_7_JUMPER_SJ | SMD solder JUMPER |  |  |  |  |  |  |  |  |  |  |  |  |  |  |  |  |  |  |  | 3
SW_DN | 2025-10-22_07-23-44_LIBRARY_EVP-AKE31ASW_EVP-AKE31A_PAN | 2025-10-22_07-23-44_LIBRARY_EVP-AKE31ASW_EVP-AKE31A_PAN | 2025-10-22_07-23-44_LIBRARY_SW_EVP-AKE31A_PAN |  |  |  |  |  | Copyright (C) 2025 Ultra Librarian. All rights reserved. |  | P123437TR-ND | P123437CT-ND | P123437DKR-ND |  |  | Panasonic | EVP-AKE31A
SW_ENT | 2025-10-22_07-23-44_LIBRARY_EVP-AKE31ASW_EVP-AKE31A_PAN | 2025-10-22_07-23-44_LIBRARY_EVP-AKE31ASW_EVP-AKE31A_PAN | 2025-10-22_07-23-44_LIBRARY_SW_EVP-AKE31A_PAN |  |  |  |  |  | Copyright (C) 2025 Ultra Librarian. All rights reserved. |  | P123437TR-ND | P123437CT-ND | P123437DKR-ND |  |  | Panasonic | EVP-AKE31A
SW_UP | 2025-10-22_07-23-44_LIBRARY_EVP-AKE31ASW_EVP-AKE31A_PAN | 2025-10-22_07-23-44_LIBRARY_EVP-AKE31ASW_EVP-AKE31A_PAN | 2025-10-22_07-23-44_LIBRARY_SW_EVP-AKE31A_PAN |  |  |  |  |  | Copyright (C) 2025 Ultra Librarian. All rights reserved. |  | P123437TR-ND | P123437CT-ND | P123437DKR-ND |  |  | Panasonic | EVP-AKE31A
TP_3V3 | HECTOR_WATCH_1_TPTP20R | HECTOR_WATCH_1_TPTP20R | HECTOR_WATCH_1_TP20R | Test pad |  |  |  |  |  |  |  |  |  |  |  |  |  |  |  |  |  |  |  | 2
TP_3V3_2 | HECTOR_WATCH_1_TPTP20R | HECTOR_WATCH_1_TPTP20R | HECTOR_WATCH_1_TP20R | Test pad |  |  |  |  |  |  |  |  |  |  |  |  |  |  |  |  |  |  |  | 2
TP_BAT_GND | HECTOR_WATCH_1_TPTP20R | HECTOR_WATCH_1_TPTP20R | HECTOR_WATCH_1_TP20R | Test pad |  |  |  |  |  |  |  |  |  |  |  |  |  |  |  |  |  |  |  | 2
TP_GND | HECTOR_WATCH_1_TPTP20R | HECTOR_WATCH_1_TPTP20R | HECTOR_WATCH_1_TP20R | Test pad |  |  |  |  |  |  |  |  |  |  |  |  |  |  |  |  |  |  |  | 2
TP_ON | HECTOR_WATCH_1_TPTP20R | HECTOR_WATCH_1_TPTP20R | HECTOR_WATCH_1_TP20R | Test pad |  |  |  |  |  |  |  |  |  |  |  |  |  |  |  |  |  |  |  | 2
TP_OP | HECTOR_WATCH_1_TPTP20R | HECTOR_WATCH_1_TPTP20R | HECTOR_WATCH_1_TP20R | Test pad |  |  |  |  |  |  |  |  |  |  |  |  |  |  |  |  |  |  |  | 2
TP_RESET | HECTOR_WATCH_1_TPTP20R | HECTOR_WATCH_1_TPTP20R | HECTOR_WATCH_1_TP20R | Test pad |  |  |  |  |  |  |  |  |  |  |  |  |  |  |  |  |  |  |  | 2
TP_SCL | HECTOR_WATCH_1_TPTP20R | HECTOR_WATCH_1_TPTP20R | HECTOR_WATCH_1_TP20R | Test pad |  |  |  |  |  |  |  |  |  |  |  |  |  |  |  |  |  |  |  | 2
TP_SDA | HECTOR_WATCH_1_TPTP20R | HECTOR_WATCH_1_TPTP20R | HECTOR_WATCH_1_TP20R | Test pad |  |  |  |  |  |  |  |  |  |  |  |  |  |  |  |  |  |  |  | 2
TP_SWDCLK | HECTOR_WATCH_1_TPTP20R | HECTOR_WATCH_1_TPTP20R | HECTOR_WATCH_1_TP20R | Test pad |  |  |  |  |  |  |  |  |  |  |  |  |  |  |  |  |  |  |  | 2
TP_SWDIO | HECTOR_WATCH_1_TPTP20R | HECTOR_WATCH_1_TPTP20R | HECTOR_WATCH_1_TP20R | Test pad |  |  |  |  |  |  |  |  |  |  |  |  |  |  |  |  |  |  |  | 2
TP_SWO | HECTOR_WATCH_1_TPTP20R | HECTOR_WATCH_1_TPTP20R | HECTOR_WATCH_1_TP20R | Test pad |  |  |  |  |  |  |  |  |  |  |  |  |  |  |  |  |  |  |  | 2
TP_VBAT | HECTOR_WATCH_1_TPTP20R | HECTOR_WATCH_1_TPTP20R | HECTOR_WATCH_1_TP20R | Test pad |  |  |  |  |  |  |  |  |  |  |  |  |  |  |  |  |  |  |  | 2
TP_VREG | HECTOR_WATCH_1_TPTP20R | HECTOR_WATCH_1_TPTP20R | HECTOR_WATCH_1_TP20R | Test pad |  |  |  |  |  |  |  |  |  |  |  |  |  |  |  |  |  |  |  | 2
U1 | NRF52840_QF | NORDIC_NRF_4_NRF52840_QF | NORDIC_NRF_4_AQFN50P700X700X85_HS-74N | nRF52840
U2 | ESP32_C6_LIBRARY_MAX17048G+T10 | ESP32_C6_LIBRARY_MAX17048G+T10 | ESP32_C6_LIBRARY_SON50P200X200X80-9N | Check availability |  |  | In Stock | https://www.snapeda.com/parts/MAX17048G+T10/Analog+Devices/view-part/?ref=eda |  | 3µA 1-Cell/2-Cell Fuel Gauge with ModelGauge |  |  |  |  |  |  |  | Analog Devices |  |  |  | MAX17048G+T10 | TDFN-8 Maxim |  | None |  | https://www.snapeda.com/api/url_track_click_mouser/?unipart_id=329239&manufacturer=Analog Devices&part_name=MAX17048G+T10&search_term=None | https://www.snapeda.com/parts/MAX17048G+T10/Analog+Devices/view-part/?ref=snap
X1 | 32MHz | NORDIC_NRF_XTAL_32MHZ | NORDIC_NRF_BT-XTAL_2016_N
X2 | 32.726kHz | NORDIC_NRF_1_XTAL_32KHZ | NORDIC_NRF_1_XTAL_3215_N

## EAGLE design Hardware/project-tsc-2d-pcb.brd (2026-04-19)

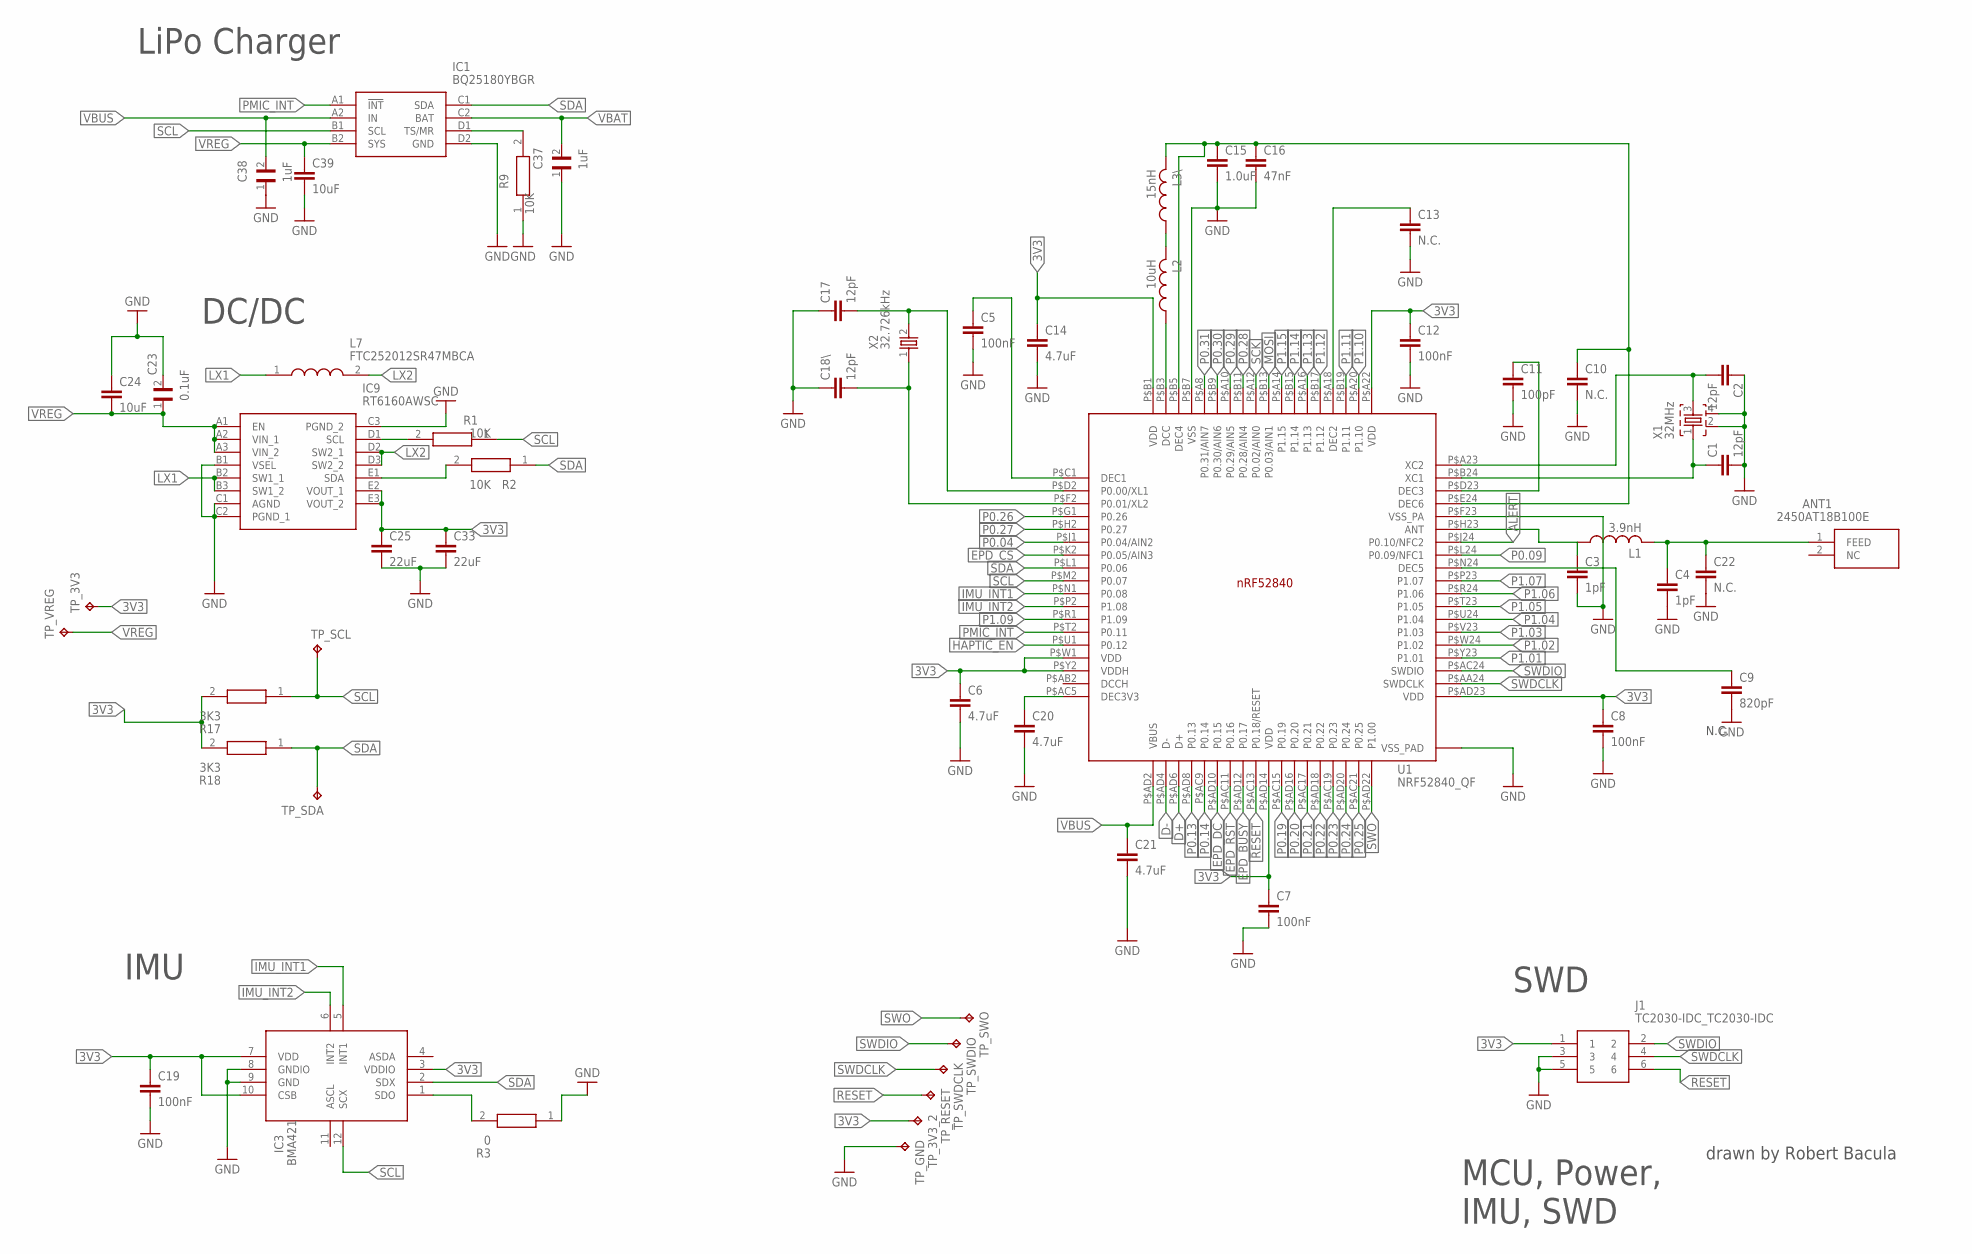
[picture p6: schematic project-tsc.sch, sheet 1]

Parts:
ANT1: 2450AT18B100E; 2450AT18B100E_ANTC3216X140N
C1, C2, C17, C18\: 12pF; NORDIC_NRF_3_RESC0201_L
C3, C4: 1pF; NORDIC_NRF_3_RESC0201_N
C5, C12, C19: 100nF; NORDIC_NRF_3_RESC0201_L
C6, C20, C21: 4.7uF; NORDIC_NRF_3_RESC0402_N
C7, C8: 100nF; NORDIC_NRF_3_RESC0201_N
C9: 820pF; NORDIC_NRF_3_RESC0201_N
C10, C13: N.C.; NORDIC_NRF_3_RESC0201_L
C11: 100pF; NORDIC_NRF_3_RESC0201_L
C14: 4.7uF; NORDIC_NRF_3_RESC0201_L
C15: 1.0uF; NORDIC_NRF_3_RESC0201_L
C16: 47nF; NORDIC_NRF_3_RESC0201_L
C22: N.C.; NORDIC_NRF_3_RESC0201_N
C23: 0.1uF; GRM011R60J152KE01L_2_CAPC0201X13N
C24, C39: 10uF; NORDIC_NRF_3_RESC0201_L
C25, C33: 22uF; NORDIC_NRF_3_RESC0201_L
C37, C38: 1uF; GRM011R60J152KE01L_2_CAPC0201X13N
IC1: BQ25180YBGR; BQ25180YBGR_BGA8C40P2X4_100X155X50
IC3: BMA421; BMA423_BMA423
IC9: RT6160AWSC; RT6160AWSC_BGA15C40P3X5_140X230X60
J1: TC2030-IDC_TC2030-IDC; TC2030-IDC_TC2030IDC
L1: 3.9nH; NORDIC_NRF_2_RESC0402_L
L2: 10uH; NORDIC_NRF_2_RESC0402_L
L3\: 15nH; NORDIC_NRF_2_RESC0402_L
L7: FTC252012SR47MBCA; MLP2016SR47MT0S1_INDC2016X100N
R1, R2, R9: 10K; CPF0201D7K68C1_0201
R3: 0; CPF0201D7K68C1_0201
R17, R18: 3K3; CPF0201D7K68C1_0201
TP_3V3, TP_3V3_2: HECTOR_WATCH_1_TPTP20R; HECTOR_WATCH_1_TP20R
TP_GND: HECTOR_WATCH_1_TPTP20R; HECTOR_WATCH_1_TP20R
TP_RESET: HECTOR_WATCH_1_TPTP20R; HECTOR_WATCH_1_TP20R
TP_SCL: HECTOR_WATCH_1_TPTP20R; HECTOR_WATCH_1_TP20R
TP_SDA: HECTOR_WATCH_1_TPTP20R; HECTOR_WATCH_1_TP20R
TP_SWDCLK: HECTOR_WATCH_1_TPTP20R; HECTOR_WATCH_1_TP20R
TP_SWDIO: HECTOR_WATCH_1_TPTP20R; HECTOR_WATCH_1_TP20R
TP_SWO: HECTOR_WATCH_1_TPTP20R; HECTOR_WATCH_1_TP20R
TP_VREG: HECTOR_WATCH_1_TPTP20R; HECTOR_WATCH_1_TP20R
U1: NRF52840_QF; NORDIC_NRF_4_AQFN50P700X700X85_HS-74N
X1: 32MHz; NORDIC_NRF_BT-XTAL_2016_N
X2: 32.726kHz; NORDIC_NRF_1_XTAL_3215_N

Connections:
3V1: C5.1, U1.P$C1 (DEC1)
3V3: C6.1, C7.1, C8.1, C12.1, C14.1, C19.1, C25.1, C33.1, IC3.3 (VDDIO), IC3.7 (VDD), IC3.10 (CSB), IC9.E2 (VOUT_1), IC9.E3 (VOUT_2), J1.1, R17.2, R18.2, TP_3V3.TP, TP_3V3_2.TP, U1.P$A22 (VDD), U1.P$AD14 (VDD), U1.P$AD23 (VDD), U1.P$B1 (VDD), U1.P$W1 (VDD), U1.P$Y2 (VDDH); also elsewhere on the board
ALERT: U1.P$J24 (P0.10/NFC2); also elsewhere on the board
D+: U1.P$AD6 (D+); also elsewhere on the board
D-: U1.P$AD4 (D-); also elsewhere on the board
EPD_BUSY: U1.P$AD12 (P0.17); also elsewhere on the board
EPD_CS: U1.P$K2 (P0.05/AIN3); also elsewhere on the board
EPD_DC: U1.P$AD10 (P0.15); also elsewhere on the board
EPD_RST: U1.P$AC11 (P0.16); also elsewhere on the board
GND: C1.2, C2.1, C3.2, C4.2, C5.2, C6.2, C7.2, C8.2, C9.2, C10.2, C11.2, C12.2, C13.2, C14.2, C15.2, C16.2, C17.1, C18\.1, C19.2, C20.2, C21.2, C22.2, C23.2, C24.1, C25.2, C33.2, C37.1, C38.1, C39.2, IC1.D2 (GND), IC3.8 (GNDIO), IC3.9 (GND), IC9.B1 (VSEL), IC9.C1 (AGND), IC9.C2 (PGND_1), IC9.C3 (PGND_2), J1.3, J1.5, R3.1, R9.1, TP_GND.TP, U1.P$74 (VSS_PAD), U1.P$75 (VSS_PAD), U1.P$76 (VSS_PAD), U1.P$77 (VSS_PAD), U1.P$78 (VSS_PAD), U1.P$79 (VSS_PAD), U1.P$80 (VSS_PAD), U1.P$81 (VSS_PAD), U1.P$82 (VSS_PAD), U1.P$83 (VSS_PAD), U1.P$84 (VSS_PAD), U1.P$85 (VSS_PAD), U1.P$86 (VSS_PAD), U1.P$87 (VSS_PAD), U1.P$88 (VSS_PAD), U1.P$89 (VSS_PAD), U1.P$90 (VSS_PAD), U1.P$B7 (VSS), U1.P$F23 (VSS_PA), X1.2, X1.4; also elsewhere on the board
GND1: C17.2, U1.P$D2 (P0.00/XL1), X2.2
GND2: C18\.2, U1.P$F2 (P0.01/XL2), X2.1
GND3: C2.2, U1.P$A23 (XC2), X1.3
HAPTIC_EN: U1.P$U1 (P0.12); also elsewhere on the board
IMU_INT1: IC3.5 (INT1), U1.P$N1 (P0.08)
IMU_INT2: IC3.6 (INT2), U1.P$P2 (P1.08)
LX1: IC9.B2 (SW1_1), IC9.B3 (SW1_2), L7.1
LX2: IC9.D2 (SW2_1), IC9.D3 (SW2_2), L7.2
MOSI: U1.P$B13 (P0.03/AIN1); also elsewhere on the board
unnamed: L2.1, U1.P$B3 (DCC)
unnamed: L2.2, L3\.1
unnamed: C10.1, C15.1, C16.1, L3\.2, U1.P$B5 (DEC4), U1.P$E24 (DEC6)
unnamed: IC1.D1 (TS/MR), R9.2
unnamed: C13.1, U1.P$A18 (DEC2)
unnamed: C11.1, U1.P$D23 (DEC3)
unnamed: C1.1, U1.P$B24 (XC1), X1.1
unnamed: IC9.D1 (SCL), R1.2
unnamed: IC9.E1 (SDA), R2.2
unnamed: IC3.1 (SDO), R3.2
unnamed: C20.1, U1.P$AC5 (DEC3V3)
unnamed: C9.1, U1.P$N24 (DEC5)
unnamed: ANT1.1 (FEED), C4.1, C22.1, L1.2
unnamed: C3.1, L1.1, U1.P$H23 (ANT)
P0.04: U1.P$J1 (P0.04/AIN2)
P0.09: U1.P$L24 (P0.09/NFC1)
P0.13: U1.P$AD8 (P0.13); also elsewhere on the board
P0.14: U1.P$AC9 (P0.14); also elsewhere on the board
P0.19: U1.P$AC15 (P0.19)
P0.20: U1.P$AD16 (P0.20)
P0.21: U1.P$AC17 (P0.21)
P0.22: U1.P$AD18 (P0.22)
P0.23: U1.P$AC19 (P0.23)
P0.24: U1.P$AD20 (P0.24)
P0.25: U1.P$AC21 (P0.25)
P0.26: U1.P$G1 (P0.26)
P0.27: U1.P$H2 (P0.27)
P0.28: U1.P$B11 (P0.28/AIN4)
P0.29: U1.P$A10 (P0.29/AIN5)
P0.30: U1.P$B9 (P0.30/AIN6)
P0.31: U1.P$A8 (P0.31/AIN7)
P1.01: U1.P$Y23 (P1.01); also elsewhere on the board
P1.02: U1.P$W24 (P1.02); also elsewhere on the board
P1.03: U1.P$V23 (P1.03)
P1.04: U1.P$U24 (P1.04)
P1.05: U1.P$T23 (P1.05)
P1.06: U1.P$R24 (P1.06)
P1.07: U1.P$P23 (P1.07)
P1.09: U1.P$R1 (P1.09)
P1.10: U1.P$A20 (P1.10)
P1.11: U1.P$B19 (P1.11)
P1.12: U1.P$B17 (P1.12)
P1.13: U1.P$A16 (P1.13)
P1.14: U1.P$B15 (P1.14)
P1.15: U1.P$A14 (P1.15)
PMIC_INT: IC1.A1 (!INT), U1.P$T2 (P0.11)
RESET: J1.6, TP_RESET.TP, U1.P$AC13 (P0.18/RESET)
SCK: U1.P$A12 (P0.02/AIN0); also elsewhere on the board
SCL: IC1.B1 (SCL), IC3.12 (SCX), R1.1, R17.1, TP_SCL.TP, U1.P$M2 (P0.07); also elsewhere on the board
SDA: IC1.C1 (SDA), IC3.2 (SDX), R2.1, R18.1, TP_SDA.TP, U1.P$L1 (P0.06); also elsewhere on the board
SWDCLK: J1.4, TP_SWDCLK.TP, U1.P$AA24 (SWDCLK)
SWDIO: J1.2, TP_SWDIO.TP, U1.P$AC24 (SWDIO)
SWO: TP_SWO.TP, U1.P$AD22 (P1.00)
VBAT: C37.2, IC1.C2 (BAT); also elsewhere on the board
VBUS: C21.1, C38.2, IC1.A2 (IN), U1.P$AD2 (VBUS); also elsewhere on the board
VREG: C23.1, C24.2, C39.1, IC1.B2 (SYS), IC9.A1 (EN), IC9.A2 (VIN_1), IC9.A3 (VIN_2), TP_VREG.TP

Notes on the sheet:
N.C.
LiPo Charger
DC/DC
IMU
SWD
MCU, Power, IMU, SWD
drawn by Robert Bacula

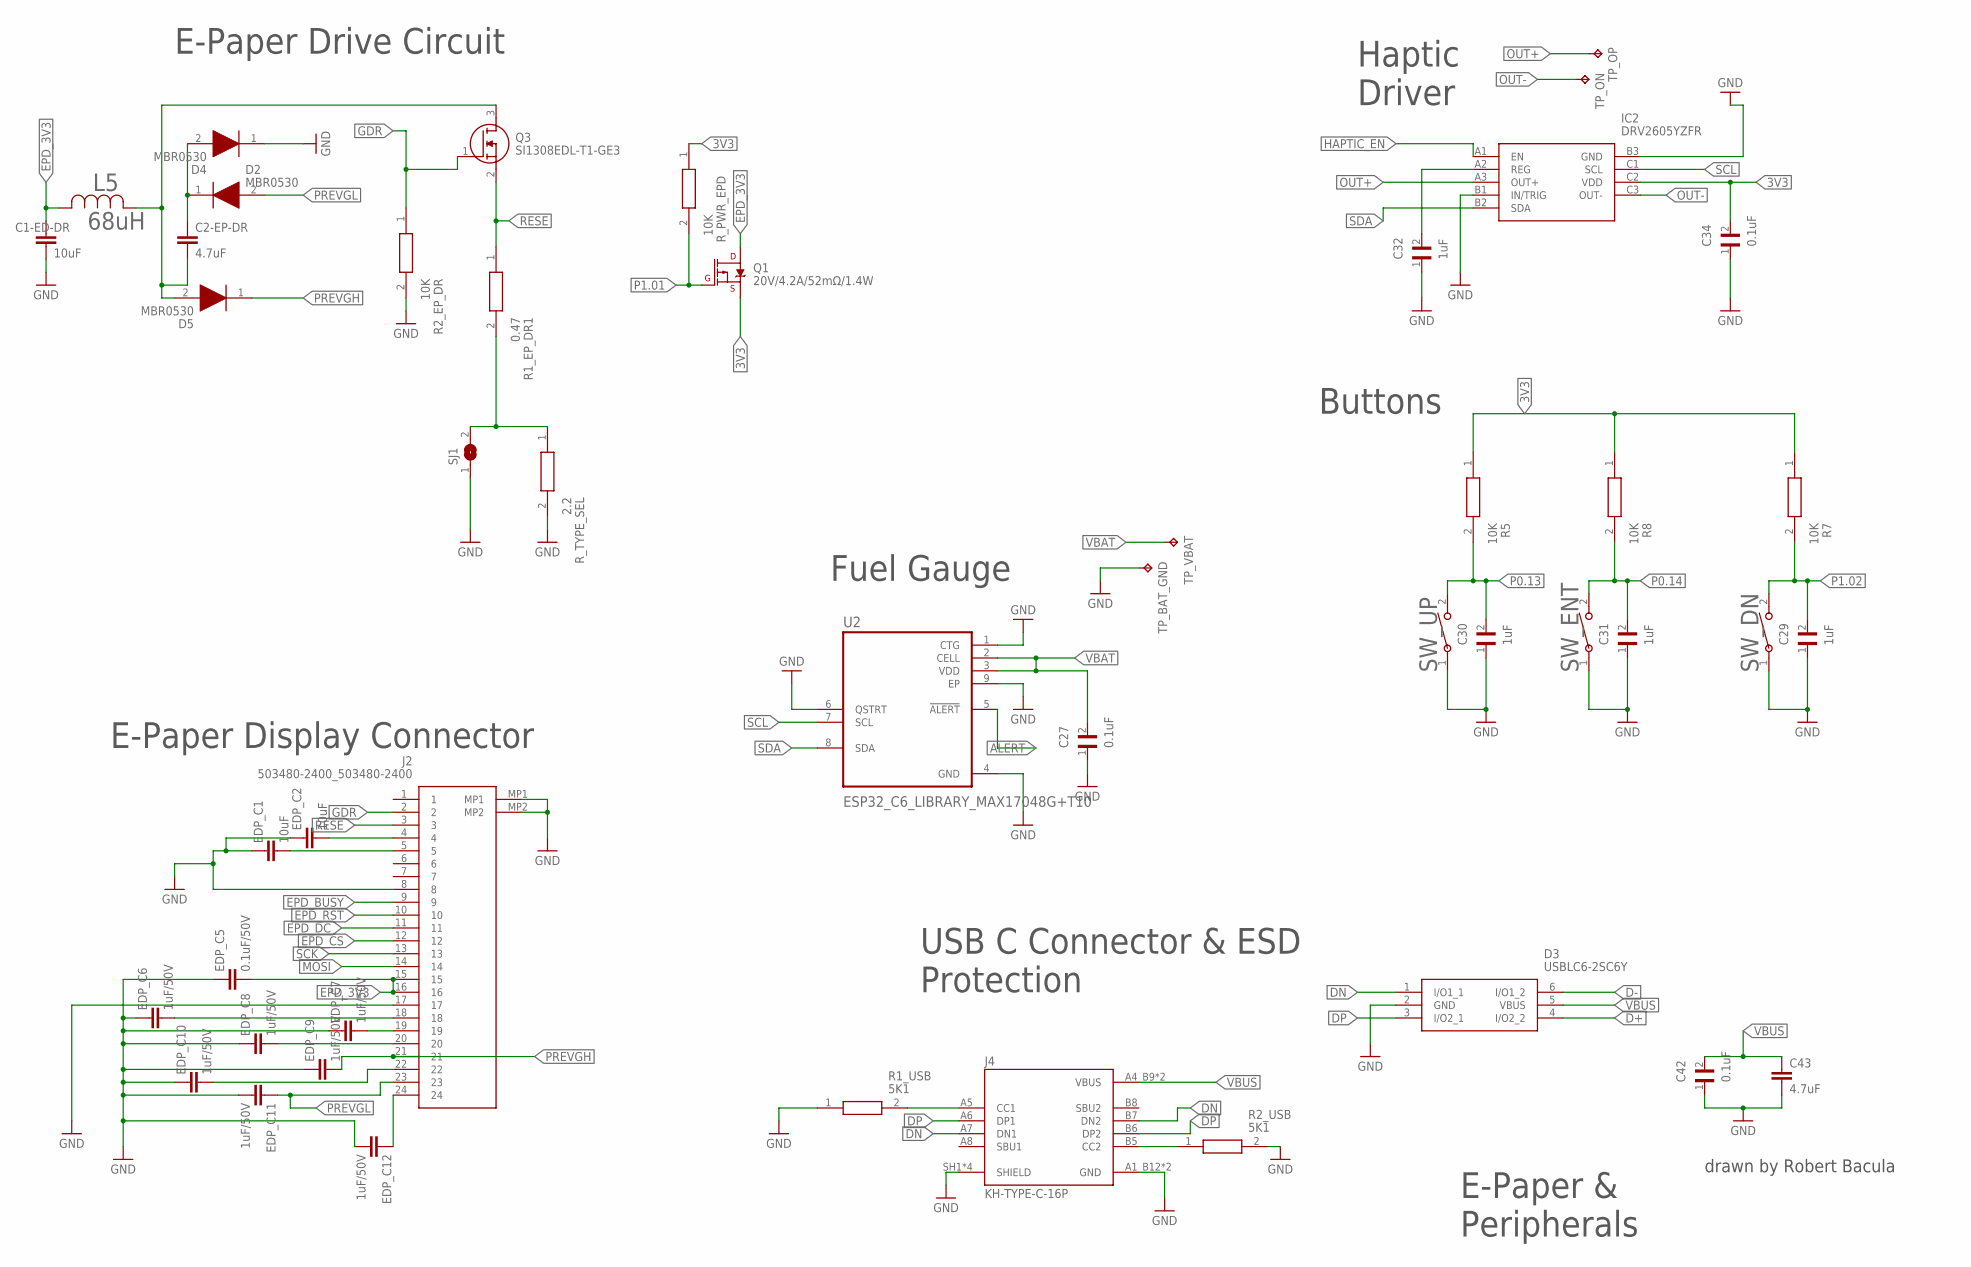
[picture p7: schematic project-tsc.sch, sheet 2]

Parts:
C1-ED-DR: 10uF; NORDIC_NRF_3_RESC0402_N
C2-EP-DR: 4.7uF; NORDIC_NRF_3_RESC0402_N
C27, C34, C42: 0.1uF; GRM011R60J152KE01L_2_CAPC0201X13N
C29, C30, C31, C32: 1uF; GRM011R60J152KE01L_2_CAPC0201X13N
C43: 4.7uF; NORDIC_NRF_3_RESC0201_L
D2, D4, D5: MBR0530; ESP32_C6_LIBRARY_5_SOD3716X135N
D3: USBLC6-2SC6Y; ESP32_C6_LIBRARY_3_SOT95P280X145-6N
EDP_C1, EDP_C2: 10uF; NORDIC_NRF_3_RESC0201_L
EDP_C5: 0.1uF/50V; NORDIC_NRF_3_RESC0201_L
EDP_C6, EDP_C7, EDP_C8, EDP_C9, EDP_C10, EDP_C11, EDP_C12: 1uF/50V; NORDIC_NRF_3_RESC0201_L
IC2: DRV2605YZFR; DRV2605YZFR_BGA9C50P3X3_144X144X62
J2: 503480-2400_503480-2400; 503480-2400_5034802400
J4: KH-TYPE-C-16P; KH-TYPE-C-16P_KINGHELM_KH-TYPE-C-16P
L5: 68uH; ESP32_C6_LIBRARY_2_IND_4828-WE-TPC_WRE
Q1: 20V/4.2A/52mΩ/1.4W; ESP32_C6_LIBRARY_4_ESP32_C6_LIBRARY_4_ESP32_C6_LIBRARY_4_ES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
Q3: SI1308EDL-T1-GE3; ESP32_C6_LIBRARY_6_SOT65P210X110-3N
R1_EP_DR1: 0.47; CPF0201D7K68C1_0201
R1_USB, R2_USB: 5K1; CPF0201D7K68C1_0201
R2_EP_DR, R5, R7, R8: 10K; CPF0201D7K68C1_0201
R_PWR_EPD: 10K; CPF0201D7K68C1_0201
R_TYPE_SEL: 2.2; CPF0201D7K68C1_0201
SJ1: ESP32_C6_LIBRARY_7_JUMPER_SJ
SW_DN: 2025-10-22_07-23-44_LIBRARY_EVP-AKE31ASW_EVP-AKE3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; 2025-10-22_07-23-44_LIBRARY_SW_EVP-AKE31A_PAN
SW_ENT: 2025-10-22_07-23-44_LIBRARY_EVP-AKE31ASW_EVP-AKE3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; 2025-10-22_07-23-44_LIBRARY_SW_EVP-AKE31A_PAN
SW_UP: 2025-10-22_07-23-44_LIBRARY_EVP-AKE31ASW_EVP-AKE3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; 2025-10-22_07-23-44_LIBRARY_SW_EVP-AKE31A_PAN
TP_BAT_GND: HECTOR_WATCH_1_TPTP20R; HECTOR_WATCH_1_TP20R
TP_ON: HECTOR_WATCH_1_TPTP20R; HECTOR_WATCH_1_TP20R
TP_OP: HECTOR_WATCH_1_TPTP20R; HECTOR_WATCH_1_TP20R
TP_VBAT: HECTOR_WATCH_1_TPTP20R; HECTOR_WATCH_1_TP20R
U2: ESP32_C6_LIBRARY_MAX17048G+T10; ESP32_C6_LIBRARY_SON50P200X200X80-9N

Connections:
3V3: C34.2, IC2.C2 (VDD), Q1.2 (S), R5.1, R7.1, R8.1, R_PWR_EPD.1; also elsewhere on the board
ALERT: U2.5 (!ALERT); also elsewhere on the board
D+: D3.4 (I/O2_2); also elsewhere on the board
D-: D3.6 (I/O1_2); also elsewhere on the board
DN: D3.1 (I/O1_1), J4.A7 (DN1), J4.B7 (DN2)
DP: D3.3 (I/O2_1), J4.A6 (DP1), J4.B6 (DP2)
EPD_3V3: C1-ED-DR.1, EDP_C5.2, J2.15, J2.16, L5.2, Q1.3 (D)
EPD_BUSY: J2.9; also elsewhere on the board
EPD_CS: J2.12; also elsewhere on the board
EPD_DC: J2.11; also elsewhere on the board
EPD_RST: J2.10; also elsewhere on the board
ESP_3V1: EDP_C6.2, J2.18
ESP_3V2: EDP_C7.2, J2.19
ESP_3V4: EDP_C8.2, J2.20
ESP_3V6: EDP_C10.2, J2.22
GDR: J2.2, Q3.1 (G), R2_EP_DR.1
GND: C1-ED-DR.2, C27.1, C29.1, C30.1, C31.1, C32.1, C34.1, C42.1, C43.2, D3.2 (GND), D4.1 (K), EDP_C1.1, EDP_C2.1, EDP_C5.1, EDP_C6.1, EDP_C7.1, EDP_C8.1, EDP_C9.1, EDP_C10.1, EDP_C11.2, EDP_C12.2, IC2.B1 (IN/TRIG), IC2.B3 (GND), J2.8, J2.17, J2.MP1, J2.MP2, J4.A1_B12 (GND), J4.A12_B1 (GND), J4.SH1 (SHIELD), J4.SH2 (SHIELD), J4.SH3 (SHIELD), J4.SH4 (SHIELD), R1_USB.1, R2_EP_DR.2, R2_USB.2, R_TYPE_SEL.2, SJ1.1, SW_DN.1, SW_ENT.1, SW_UP.1, TP_BAT_GND.TP, U2.1 (CTG), U2.4 (GND), U2.6 (QSTRT), U2.9 (EP); also elsewhere on the board
HAPTIC_EN: IC2.A1 (EN); also elsewhere on the board
MOSI: J2.14; also elsewhere on the board
unnamed: R1_EP_DR1.2, R_TYPE_SEL.1, SJ1.2
unnamed: C2-EP-DR.2, D5.2 (A), L5.1, Q3.3 (D)
unnamed: C2-EP-DR.1, D2.1 (K), D4.2 (A)
unnamed: J4.A5 (CC1), R1_USB.2
unnamed: J4.B5 (CC2), R2_USB.1
unnamed: EDP_C2.2, J2.4
unnamed: EDP_C1.2, J2.5
unnamed: C32.2, IC2.A2 (REG)
unnamed: EDP_C12.1, J2.24
OUT+: IC2.A3 (OUT+), TP_OP.TP
OUT-: IC2.C3 (OUT-), TP_ON.TP
P0.13: C30.2, R5.2, SW_UP.2; also elsewhere on the board
P0.14: C31.2, R8.2, SW_ENT.2; also elsewhere on the board
P1.01: Q1.1 (G), R_PWR_EPD.2; also elsewhere on the board
P1.02: C29.2, R7.2, SW_DN.2; also elsewhere on the board
PREVGH: D5.1 (K), EDP_C9.2, J2.21
PREVGL: D2.2 (A), EDP_C11.1, J2.23
RESE: J2.3, Q3.2 (S), R1_EP_DR1.1
SCK: J2.13; also elsewhere on the board
SCL: IC2.C1 (SCL), U2.7 (SCL); also elsewhere on the board
SDA: IC2.B2 (SDA), U2.8 (SDA); also elsewhere on the board
VBAT: C27.2, TP_VBAT.TP, U2.2 (CELL), U2.3 (VDD); also elsewhere on the board
VBUS: C42.2, C43.1, D3.5 (VBUS), J4.A4_B9 (VBUS), J4.A9_B4 (VBUS); also elsewhere on the board

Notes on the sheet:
Fuel Gauge
E-Paper Display Connector
E-Paper Drive Circuit
USB C Connector & ESD Protection
Haptic Driver
Buttons
E-Paper & Peripherals
drawn by Robert Bacula

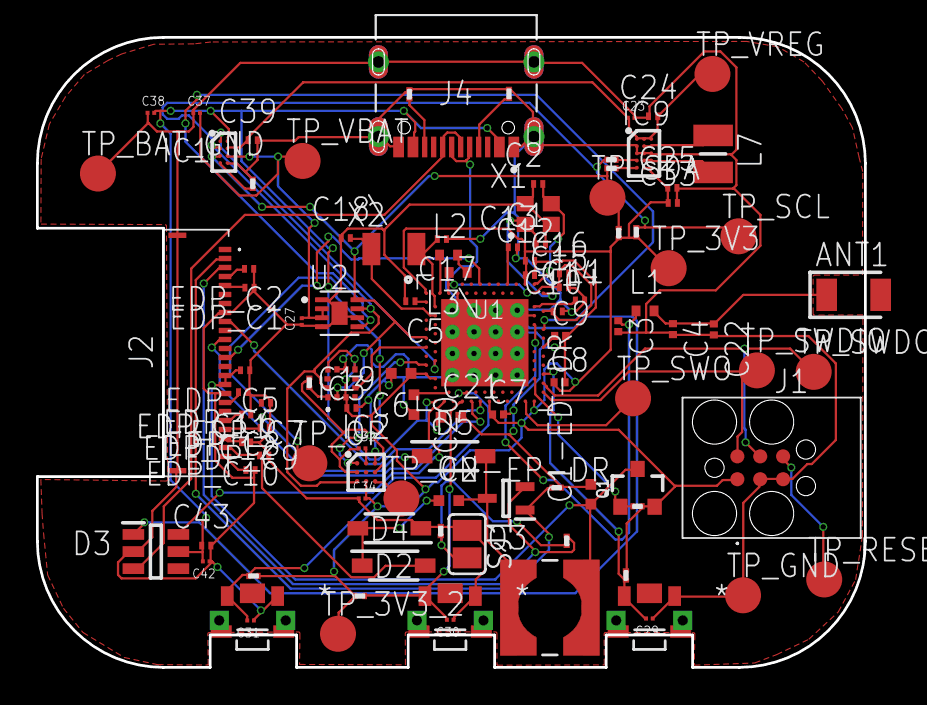
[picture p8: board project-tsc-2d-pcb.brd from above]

Board: 2 copper layers, 46.0 x 35.0 mm, 105 parts (0 on the bottom side), 70 nets.

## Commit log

2026-04-19 review changes
    [InkTime.sch, PCB.brd, project-tsc-2d-pcb.brd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]
2026-04-19 added .cpl and .bom files
    [BOM.csv]

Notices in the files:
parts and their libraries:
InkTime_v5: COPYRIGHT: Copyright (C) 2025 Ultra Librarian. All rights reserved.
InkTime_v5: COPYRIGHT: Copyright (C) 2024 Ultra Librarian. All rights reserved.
